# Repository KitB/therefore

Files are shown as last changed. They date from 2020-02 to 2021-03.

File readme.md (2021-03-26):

# Therefore Mechanical Keyboard

Therefore is a from-scratch ergodox clone focussing on ease of use between
multiple computers in multiple locations and firmware written in Python for ease
of customization.

### Design goals:

* USB-C, BLE, NRF24L01 dongle, and possibly Logitech Unifying Receiver
  connectivity
* Wireless split alongside TRRS as an option
* Compact and low-profile, designed for portability ("portodox" was a candidate
  name)
* Carrying case or magnetic snap-together of the halves
* Either easy-to-source parts (e.g. adafruit and bog-standard components) or
  a single PCB with everything on it manufactured by e.g. JLCPCB.
  
### Non-goals:

* Low latency: this is not a gaming keyboard; latency between split halves is
  important for avoiding transposition errors though.
* USB Hub: Sadly not possible over the wireless protocols.
* Adjustments to normal ergodox layout: In particular no adjustments will be
  made in the name of compactness; the goal is to make it as compact as possible
  within the layout of the normal ergodox.

 ## State of affairs
 I am typing this on a therefore made out of PCBs manufactured by JLCPCB with
 a case I 3d printed (and then cut up a little to make a bigger hole for USB
 cables). Each half has a Adafruit Feather NRF52840 and a hand-wired TRRS
 connector. It is very much a prototype but I have been typing on this
 keyboard alone for months now.
 
 Code for fully wireless operation is present and functional but latency between
 halves ruins it; I don't think this is inherent in BLE, just present in this
 implementation.
 
 ## License
 The firmware is BSD 3-clause licensed (see [firmware/python/LICENSE ](firmware/python/LICENSE))
 but the hardware is currently all-rights-reserved.
 It will in future be open source or at least free for non-commercial use.

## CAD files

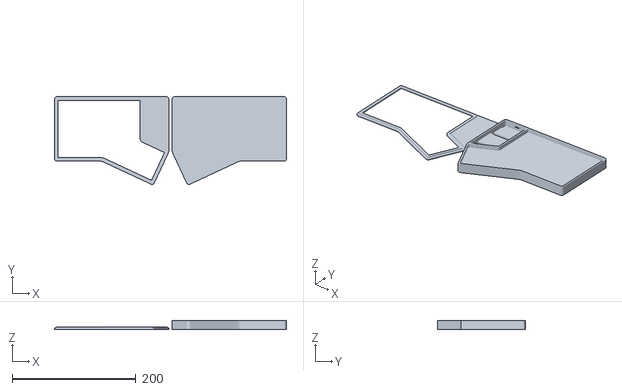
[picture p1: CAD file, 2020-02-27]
hardware/case/biglid/demo.stl
374.6 x 141.8 x 14.0

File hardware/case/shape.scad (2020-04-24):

use <BOSL/math.scad>;
x0 = 0;
xn = 183;

x2 = 141.6;
x3 = xn - 23.54;
x1 = x3 - 79.76;


y0 = 0;
yn = 137;

y1 = 66.71;
y2 = y1 + 18.98;
y3 = yn - 37.2;

bounding_points = [
[x0, y0],
[x2, y0],
[x2, y1],
[xn, y2],
[x3, yn],
[x1, y3],
[x0, y3],
[x0, y0],
];

module bounding_path () {
  mirror([0, 1, 0])
    polygon(points = bounding_points);
}

case_points = [
[x0, y0],
[xn, y0],
[xn, y2],
[x3, yn],
[x1, y3],
[x0, y3],
[x0, y0],
];

module case_path () {
  polygon(points = case_points);
}

sx0 = 0;
sxn = 15.61;
sxcut = 0.813;

sy0 = 0;
syn = 14;
sycut = 9.503 - 4.494;

switch_hole_points = [];


function cat (LS) = [for (L = LS, a = L) a];
function add (mat, vec) = [for (mv = mat) mv + vec];
function mul (mat, vec) = [for (mv = mat) vmul(mv, vec)];
function pad_angles (locations) = [for (loc = locations) concat(loc, [0])];

inter_switch_distance = 19.06;
d = 19.06;

finger_locations = pad_angles([
  [0,        0], [d,     0], [2 * d,    -1.27], [3 * d,    -2.82], [4 * d,    -1.27], [5 * d,     1.9], [6.25 * d,     1.9],
  [0, 1.25 * d], [d,     d], [2 * d,     d - 1.27], [3 * d,     d - 2.82], [4 * d,     d - 1.27], [5 * d,     d + 1.9], [6.25 * d,     d + 1.9],
                 [d, 2 * d], [2 * d, 2 * d - 1.27], [3 * d, 2 * d - 2.82], [4 * d, 2 * d - 1.27], [5 * d, 2 * d + 1.9], [6.25 * d, 2 * d + 1.9],
  [0, 2.75 * d], [d, 3 * d], [2 * d, 3 * d - 1.27], [3 * d, 3 * d - 2.82], [4 * d, 3 * d - 1.27], [5 * d, 3 * d + 1.9], [6.25 * d, 3 * d + 1.9],
                             [2 * d, 4 * d - 1.27], [3 * d, 4 * d - 2.82], [4 * d, 4 * d - 1.27], [5 * d, 4 * d + 1.9], [   6 * d, 4 * d + 1.9],
]);

a = -25;
thumb_locations = rot(a, cp=[3 * d + 7, 4 * d - 2.82, 0], p=add([
  [d - 14 , d * 2.75 + 14, a],
  [0 - 14 , d * 2.75 + 14, a],
  [0 - 14 , d * 1.25 + 14, a],
  [-d - 14 , d * 1.25 + 14, a],
  [-d - 14 , d * 2.25 + 14, a],
  [-d - 14 , d * 3.25 + 14, a],
], [3, -3.3, 0]));

_switch_locations = concat(finger_locations, thumb_locations);

switch_locations = add(mul(_switch_locations, [-1, 1, -1]), [xn - 10 - 40.73, 7 + 4.62, 0]);

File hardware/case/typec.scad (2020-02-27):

$fn = 100;

sheath_outer_width = 2.6;
sheath_outer_length = 8.4;

module typec_sheath_outer() {
  module end_cylinder() {
    circle(sheath_outer_width / 2);
  }

  translate([-(sheath_outer_length - sheath_outer_width) / 2, 0, 0])
  union() {
    end_cylinder();
    translate([0, - (sheath_outer_width / 2), 0])
      square([sheath_outer_length - sheath_outer_width, sheath_outer_width]);
    translate([sheath_outer_length - sheath_outer_width, 0, 0])
    end_cylinder();
  }
}

module typec_sheath_inner() {
  offset(r=-0.3) typec_sheath_outer();
}

module typec_male(length=6) {
  linear_extrude(length)
  difference() {
    typec_sheath_outer();
    typec_sheath_inner();
  }
}

typec_male();

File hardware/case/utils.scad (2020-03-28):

module pnp(locations) {
  for (loc = locations) {
    x = loc[0];
    y = loc[1];
    a = loc[2];
    translate([x, y])
    rotate(a)
    children();
  }
}

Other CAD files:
hardware/case/biglid/case.scad
hardware/case/biglid/case_main.scad
hardware/case/biglid/demo.scad
hardware/case/biglid/lid.scad
hardware/case/biglid/plate.scad
hardware/case/screwless/case.scad
hardware/case/screwless/printing/base.scad
hardware/case/screwless/printing/innards.scad
hardware/case/screwy/case.scad

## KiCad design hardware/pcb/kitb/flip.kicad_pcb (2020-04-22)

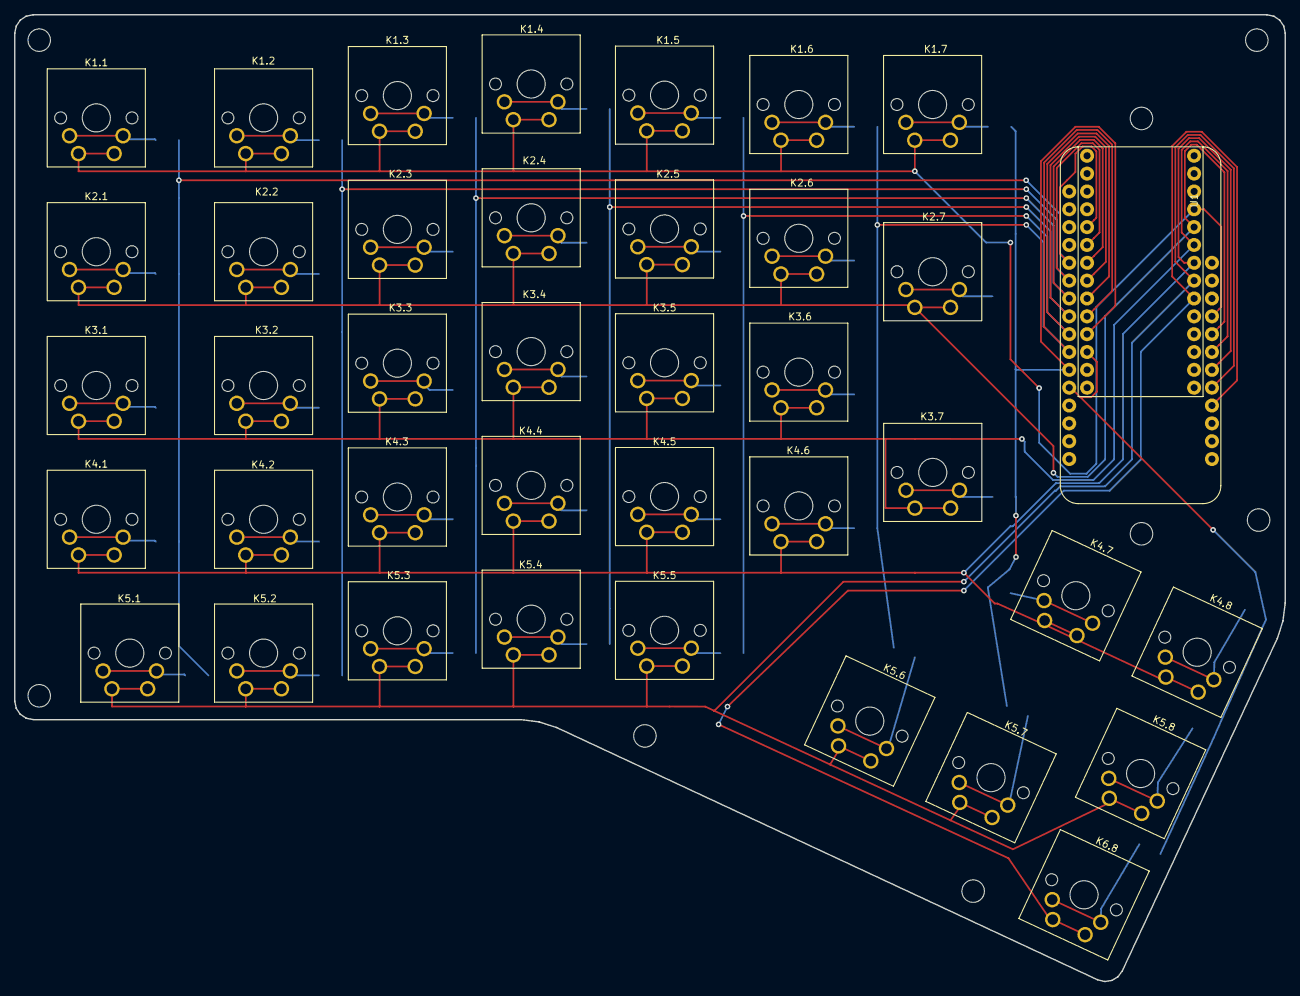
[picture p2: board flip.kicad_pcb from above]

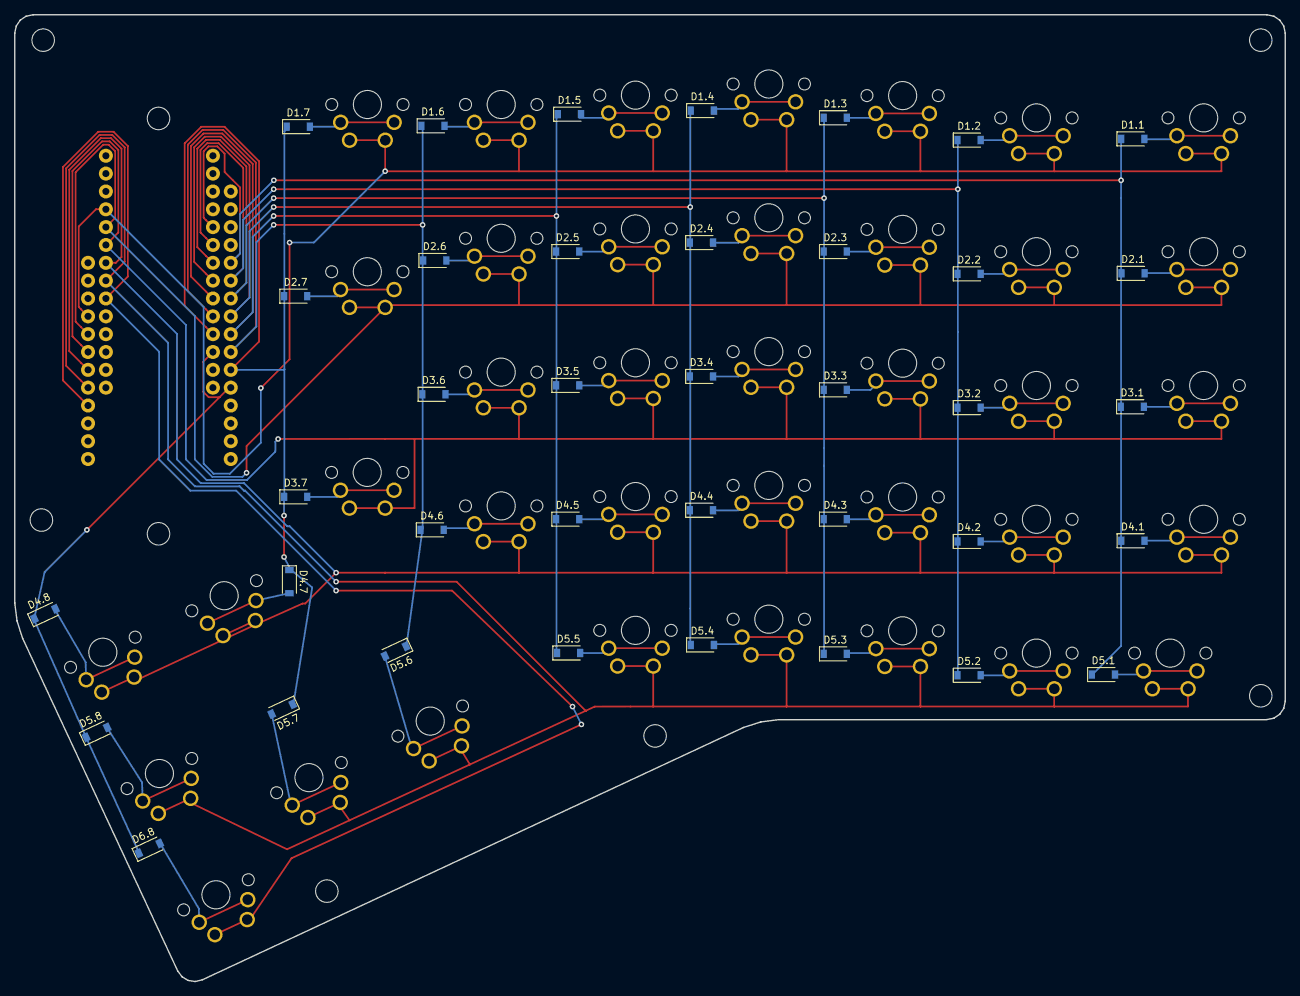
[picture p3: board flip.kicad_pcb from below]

Board: 2 copper layers, 180.9 x 137.6 mm, 77 parts (38 on the bottom side), 52 nets.

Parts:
D1.1, D1.2, D1.3, D1.4, D1.5, D1.6, D1.7, D2.1, D2.2, D2.3, D2.4, D2.5, D2.6, D2.7, D3.1, D3.2, D3.3, D3.4, D3.5, D3.6, D3.7, D4.1, D4.2, D4.3, D4.4, D4.5, D4.6, D4.7, D4.8, D5.1, D5.2, D5.3, D5.4, D5.5, D5.6, D5.7, D5.8, D6.8: D; D_SOD-123
K1.1, K2.1, K3.1, K4.1: switch; SW_Cherry_MX1A_1.50u_PCB_ra
K1.2, K1.3, K1.4, K1.5, K1.6, K1.7, K2.2, K2.3, K2.4, K2.5, K2.6, K3.2, K3.3, K3.4, K3.5, K3.6, K4.2, K4.3, K4.4, K4.5, K4.6, K4.7, K4.8, K5.1, K5.2, K5.3, K5.4, K5.5, K5.8, K6.8: switch; SW_Cherry_MX1A_1.00u_PCB_ra
K2.7, K3.7: switch; SW_Cherry_MX1A_1.50u_PCB
K5.6, K5.7: switch; SW_Cherry_MX1A_2.00u_Vertical_PCB
U1: MCU; mcu

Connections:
unnamed: D1.1.1, D2.1.1, D3.1.1, D4.1.1, D5.1.1, U1.A0
unnamed: D1.1.2, K1.1.2
unnamed: D1.2.1, D2.2.1, D3.2.1, D4.2.1, D5.2.1, U1.A1
unnamed: D1.2.2, K1.2.2
unnamed: D1.3.1, D2.3.1, D3.3.1, D4.3.1, D5.3.1, U1.A2
unnamed: D1.3.2, K1.3.2
unnamed: D1.4.1, D2.4.1, D3.4.1, D4.4.1, D5.4.1, U1.A3
unnamed: D1.4.2, K1.4.2
unnamed: D1.5.1, D2.5.1, D3.5.1, D4.5.1, D5.5.1, U1.A4
unnamed: D1.5.2, K1.5.2
unnamed: D1.6.1, D2.6.1, D3.6.1, D4.6.1, D5.6.1, U1.A5
unnamed: D1.6.2, K1.6.2
unnamed: D1.7.1, D2.7.1, D3.7.1, D4.7.1, D5.7.1, U1.SCK
unnamed: D1.7.2, K1.7.2
unnamed: D2.1.2, K2.1.2
unnamed: D2.2.2, K2.2.2
unnamed: D2.3.2, K2.3.2
unnamed: D2.4.2, K2.4.2
unnamed: D2.5.2, K2.5.2
unnamed: D2.6.2, K2.6.2
unnamed: D2.7.2, K2.7.2
unnamed: D3.1.2, K3.1.2
unnamed: D3.2.2, K3.2.2
unnamed: D3.3.2, K3.3.2
unnamed: D3.4.2, K3.4.2
unnamed: D3.5.2, K3.5.2
unnamed: D3.6.2, K3.6.2
unnamed: D3.7.2, K3.7.2
unnamed: D4.1.2, K4.1.2
unnamed: D4.2.2, K4.2.2
unnamed: D4.3.2, K4.3.2
unnamed: D4.4.2, K4.4.2
unnamed: D4.5.2, K4.5.2
unnamed: D4.6.2, K4.6.2
unnamed: D4.7.2, K4.7.2
unnamed: D4.8.1, D5.8.1, D6.8.1, U1.MO
unnamed: D4.8.2, K4.8.2
unnamed: D5.1.2, K5.1.2
unnamed: D5.2.2, K5.2.2
unnamed: D5.3.2, K5.3.2
unnamed: D5.4.2, K5.4.2
unnamed: D5.5.2, K5.5.2
unnamed: D5.6.2, K5.6.2
unnamed: D5.7.2, K5.7.2
unnamed: D5.8.2, K5.8.2
unnamed: D6.8.2, K6.8.2
unnamed: K1.1.1, K1.2.1, K1.3.1, K1.4.1, K1.5.1, K1.6.1, K1.7.1, U1.13
unnamed: K2.1.1, K2.2.1, K2.3.1, K2.4.1, K2.5.1, K2.6.1, K2.7.1, U1.12
unnamed: K3.1.1, K3.2.1, K3.3.1, K3.4.1, K3.5.1, K3.6.1, K3.7.1, U1.11
unnamed: K4.1.1, K4.2.1, K4.3.1, K4.4.1, K4.5.1, K4.6.1, K4.7.1, K4.8.1, U1.10
unnamed: K5.1.1, K5.2.1, K5.3.1, K5.4.1, K5.5.1, K5.6.1, K5.7.1, K5.8.1, U1.9
unnamed: K6.8.1, U1.7,6

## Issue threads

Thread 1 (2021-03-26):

Figure out a maximum latency between boards for reasonable use

KitB, 2021-03-26:
probably by using the TRRS mode and just adding artificial latency until transposition errors occur when typing normally.

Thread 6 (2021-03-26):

USB connected detection

KitB, 2021-03-26:
Used to:

* select USB mode rather than BLE
* auto-select hero/sidekick mode

KitB, 2021-03-26:
Looks like CircuitPython closed their version of this issue 8 days ago so it's trivial now:

adafruit/circuitpython#544

https://circuitpython.readthedocs.io/en/latest/shared-bindings/supervisor/index.html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

Closed 2021-03-26.

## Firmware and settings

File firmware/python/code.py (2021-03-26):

import board
import busio
import storage
import neopixel

from therefore import usb, readkeys, ble, mesh, layout, layout_handling
from therefore.layout_handling import LayoutHandler, parse_layout
from therefore.writekeys import Output

from _bleio import ConnectionError

DEBUG = True
VERBOSE = False

if DEBUG:
    def debug(msg):
        print(msg)
else:
    def debug(msg):
        pass

if VERBOSE:
    def verbose(msg):
        debug(msg)
else:
    def verbose(msg):
        pass

HAND = storage.getmount('/').label.lower()
for entry in storage.getmount('/').ilistdir('/'):
    if entry[0].lower() == 'left':
        HAND = 'left'

keypad = readkeys.Keypad(HAND)

led = neopixel.NeoPixel(board.NEOPIXEL, 1, pixel_order=neopixel.GRB)
led.brightness = 0.01


# TODO: battery charge tracking

# this would be an enum but circuitpython doesn't implement them.
class State:
    none = 'none'
    start = 'start'
    meshing = 'meshing'
    mesh_connected = 'mesh connected'
    usb = 'usb'
    ble_connected = 'ble connected'
    ble_unconnected = 'ble unconnected'
    ble_advertising = 'ble advertising'
    hero = 'hero'
    sidekick = 'sidekick'


class MainProcess:
    def __init__(self, usb_handler, ble_handler, clock_rate=300):
        self.usb_handler = usb_handler
        self.ble_handler = ble_handler
        self.clock_rate = clock_rate

        self.previous = set()
        self._state = State.none
        self.previous_state = None
        self.state = State.start  # also sets handler
        self.advertising = False
        self.pool = mesh.WiredNegotiations(hand=HAND)
        self.remote_keys = None

        self.mode = 'usb_only'

    def run(self):
        while True:
            try:
                self.act()
            except (OSError, IndexError, ConnectionError, ValueError) as e:
                import sys
                print('=' * 80)
                sys.print_exception(e)
                self.state = State.start

    @property
    def state(self) -> str:
        return self._state

    @state.setter
    def state(self, newval: str):
        if newval != self._state:
            debug(self._state + ' -> ' + newval)

            if newval == State.ble_connected:
                led[0] = (0, 0, 255)
                self.handler = self.ble_handler()
            elif newval == State.usb:
                led[0] = 0x00_FF_00
                self.handler = self.usb_handler()
            elif newval == State.ble_advertising:
                led[0] = (32, 0, 255)
            elif newval == State.start:
                led[0] = (32, 32, 0)
            elif newval == State.sidekick:
                led[0] = 0xFF_FF_FF

            self._state = newval

    @property
    def mode(self):
        return self._mode

    @mode.setter
    def mode(self, mode):
        self._mode = mode

    def act(self):
        s = self.state
        getattr(self, 'handle_' + self.state.replace(' ', '_'))()

    def handle_start(self):
        self.state = State.meshing

    def handle_meshing(self):
        self.pool.connect()
        self.uart = self.pool.uart
        self.role = self.pool.my_role
        self.state = State.mesh_connected

    def handle_mesh_connected(self):
        if self.role == 'batman':
            self.state = State.hero
        elif self.role == 'robin':
            self.state = State.sidekick

    def handle_hero(self):
        if self.mode == 'usb_only':
            self.state = State.usb
        elif self.mode == 'ble_only':
            self.state = State.ble_unconnected

    def handle_keypresses(self):
        local_pressed = set(keypad.pressed)
        remote_pressed = set(self.uart.keys_pressed)
        current = set(local_pressed) | set(remote_pressed)

        new = current - self.previous
        gone = self.previous - current

        if new:
            verbose('New: %s' % new)
            for x, y in new:
                self.handler.press(x, y)
                # TODO: removed syskey handling from here, need to add back in for :switch
        if gone:
            verbose('Gone: %s' % gone)
            for x, y in gone:
                self.handler.release(x, y)

        if new | gone:
            verbose('Current: %s' % current)

        self.previous = current

    def handle_sidekick(self):
        self.uart.keys_pressed = keypad.pressed

    def handle_usb(self):
        self.handle_keypresses()

    def handle_ble_connected(self):
        if not ble.ble.connected:
            self.state = State.start
            return
        self.handle_keypresses()

    def handle_ble_unconnected(self):
        ble.advertise()
        self.state = State.ble_advertising

    def handle_ble_advertising(self):
        if ble.connected():
            self.state = State.ble_connected

    def handle_syskey(self, keycode):
        if keycode == 'switch':
            if self.mode == 'usb_only':
                self.mode = 'ble_only'
            elif self.mode == 'ble_only':
                self.mode = 'usb_only'
            self.state = State.mesh_connected


if __name__ == '__main__':
    parsed_layout = parse_layout(layout.layout['layers'])


    def get_ble_keyboard():
        output = Output(
            keyboard=ble.get_keyboard(),
            consumer_control=ble.get_consumer_control(),
        )
        return LayoutHandler(
            parsed_layout=parsed_layout,
            emit_press_callable=output.press,
            emit_release_callable=output.release,
        )


    def get_usb_keyboard():
        output = Output(
            keyboard=usb.get_keyboard(),
            consumer_control=usb.get_consumer_control(),
        )
        return LayoutHandler(
            parsed_layout=parsed_layout,
            emit_press_callable=output.press,
            emit_release_callable=output.release,
        )


    while True:
        try:
            runner = MainProcess(get_usb_keyboard, get_ble_keyboard)
        except OSError as e:
            led[0] = (255, 255, 255, 1)
            break
        try:
            runner.run()
        except OSError as e:
            led[0] = (255, 0, 255, 1)

    while True:
        pass

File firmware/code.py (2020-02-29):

import time

import adafruit_dotstar
import board
import busio
import math
import storage

from therefore import usb, readkeys, ble, mesh, layout
from therefore.writekeys import Output, Layout, SystemKeyPressed

uart = busio.UART(board.TX, board.RX, baudrate=9600, timeout=100)

DEBUG = True
VERBOSE = False

if DEBUG:
    def debug(msg):
        print(msg)
        uart.write((msg + '\r\n').encode('utf-8'))
else:
    def debug(msg):
        pass

if VERBOSE:
    def verbose(msg):
        debug(msg)
else:
    def verbose(msg):
        pass

HAND = storage.getmount('/').label.lower()

keypad = readkeys.Keypad(HAND)

led = adafruit_dotstar.DotStar(board.APA102_SCK, board.APA102_MOSI, 1)
led.brightness = 0.3

START = 'start'
MESHING = 'meshing'
MESH_CONNECTED = 'mesh connected'
USB = 'usb'
BLE_CONNECTED = 'ble connected'
BLE_UNCONNECTED = 'ble unconnected'
BLE_ADVERTISING = 'ble advertising'
HERO = 'hero'
HERO_BLE = 'hero ble'
HERO_USB = 'hero usb'
SIDEKICK = 'sidekick'


class MainProcess:
    def __init__(self, usb_keyboard, ble_keyboard, clock_rate=300):
        self.usb_keyboard = usb_keyboard
        self.ble_keyboard = ble_keyboard
        self.clock_rate = clock_rate

        self.previous = set()
        self._state = 'none'
        self.state = START  # also sets output
        self.previous_state = None
        self.advertising = False
        self.pool = mesh.Negotiations(hand=HAND)
        self.remote_keys = None

        self.mode = 'usb_only'

    @property
    def mode(self):
        return self._mode

    @mode.setter
    def mode(self, mode):
        self._mode = mode
        if mode == 'usb_only':
            self.output = self.usb_keyboard()
        elif mode == 'ble_only':
            self.output = self.ble_keyboard()


    def run(self):
        while True:
            try:
                self.act()
            except OSError:
                self.state = START

    @property
    def state(self):
        return self._state

    @state.setter
    def state(self, newval):
        if newval != self._state:
            debug(self._state + ' -> ' + newval)

            if newval == BLE_CONNECTED:
                led[0] = (0, 0, 32)
            elif newval == USB:
                led[0] = (32, 0, 0)
            elif newval == BLE_ADVERTISING:
                led[0] = (4, 0, 32)
            elif newval == START:
                led[0] = (32, 32, 0)

            self._state = newval

    def act(self):
        s = self.state
        getattr(self, 'handle_' + self.state.replace(' ', '_'))()

    def handle_start(self):
        self.state = MESHING

    def handle_meshing(self):
        self.pool.connect()
        self.uart = self.pool.uart
        self.role = self.pool.my_role
        self.state = MESH_CONNECTED

    def handle_mesh_connected(self):
        if self.role == 'batman':
            self.state = HERO
        elif self.role == 'robin':
            self.state = SIDEKICK

    def handle_hero(self):
        if self.mode == 'usb_only':
            self.state = USB
        elif self.mode == 'ble_only':
            self.state = BLE_UNCONNECTED

    def handle_keypresses(self):
        local_pressed = set(keypad.pressed)
        remote_pressed = set(self.uart.keys_pressed)
        current = set(local_pressed) | set(remote_pressed)

        new = current - self.previous
        gone = self.previous - current

        if new:
            verbose('New: %s' % new)
            for kc in new:
                try:
                    self.output.press(kc)
                except SystemKeyPressed as e:
                    self.handle_syskey(e.keycode)
        if gone:
            verbose('Gone: %s' % gone)
            for kc in gone:
                self.output.release(kc)

        if new | gone:
            verbose('Current: %s' % current)

        self.previous = current

    def handle_sidekick(self):
        self.uart.keys_pressed = keypad.pressed

    def handle_usb(self):
        self.handle_keypresses()

    def handle_ble_connected(self):
        if not ble.ble.connected:
            self.state = START
            return
        self.handle_keypresses()

    def handle_ble_unconnected(self):
        ble.advertise()
        self.state = BLE_ADVERTISING

    def handle_ble_advertising(self):
        if ble.connected():
            self.state = BLE_CONNECTED

    def handle_syskey(self, keycode):
        if keycode == 'switch':
            if self.mode == 'usb_only':
                self.mode = 'ble_only'
            elif self.mode == 'ble_only':
                self.mode = 'usb_only'
            self.state = MESH_CONNECTED


if __name__ == '__main__':
    layout = Layout(layout.layout)  # layout


    def get_ble_keyboard():
        return Output(
            layout=layout,
            keyboard=ble.get_keyboard(),
        )


    def get_usb_keyboard():
        return Output(
            layout=layout,
            keyboard=usb.get_keyboard(),
        )


    while True:
        runner = MainProcess(get_usb_keyboard, get_ble_keyboard)
        runner.run()

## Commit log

2020-02-27 Make case.scad render the default as an example
    rather than just being broken.
    [case.scad]
2020-02-27 Add basic USB firmware
    next up: BLE HID
    then: auto switch
2020-02-27 Modularise the current firmware
2020-02-28 Largely working auto-switch between USB and BLE
2020-02-29 Full two-hand with BLE bridge
    Doesn't auto-switch between usb and ble, that shit didn't work very
    well.
    [ble.py, code.py, mesh.py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]
2020-03-04 Layout fixes and make space for potential alternative firmwares
    [ble.py, code.py, layout.py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]
2020-03-04 Switch to something that starts to look like an enum for state
2020-03-28 Add screwless case
    [base.scad, case.scad, innards.scad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]
2020-04-22 Add source files for current PCB
    Maybe? I'm not sure exactly how much is necessary.
    [flip.kicad_pcb, therefore.sch]
2020-04-24 Update key layout to match actual PCB
    [shape.scad]
2020-04-24 Add first finished screwy case
    Planning some changes but I've actually produced this case and it works.
    Mostly.
    [case.scad]
2020-10-30 Use UART over TRRS for the time being
    BLE latency is too high, transposition errors abound. Might just be to
    do with circuitpython's BLE implementation.
    [code.py, mesh.py]
2021-03-25 Add currently-unused-but-tested layout handling
    This is the better layer implementation. Still need to hook it up to the
    rest of the firmware.
